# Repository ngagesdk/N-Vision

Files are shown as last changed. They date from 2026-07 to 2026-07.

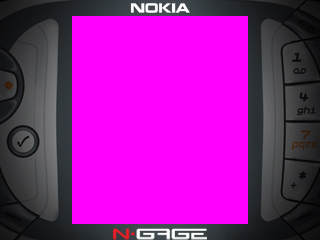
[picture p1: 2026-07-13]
firmware/assets/frame_buffer_rgb565.png

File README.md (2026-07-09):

N-Vision

# N-Vision

**A modern replacement for the original Nokia N-Gage screen capture hardware.**

## Overview

N-Vision is an open-source hardware project that aims to recreate the functionality
of the extremely rare screen capture device that was once used by Nokia during
promotional events, game demonstrations, and for recording official N-Gage gameplay
footage.

As original capture units have become virtually impossible to find, preserving and
showcasing N-Gage software has become increasingly difficult. N-Vision provides a
modern alternative by tapping directly into the display interface without requiring
any modifications to the console itself.

The project uses a custom flexible PCB (FPC) that is installed between the N-Gage's
mainboard and LCD, allowing the display signals to be captured transparently.
A Raspberry Pi Pico 2 then decodes the display data in real time and outputs it over
DVI, making it suitable for recording, streaming, or development purposes.

## Features (Planned)

- Non-destructive installation using a custom flexible PCB
- Real-time LCD signal capture
- Display decoding on a Raspberry Pi Pico 2
- Digital DVI video output
- Open-source hardware and firmware
- Designed specifically for the Nokia N-Gage Classic

## Project Structure
 
| Directory | Description |
| :--- | :--- |
| [decoder/](decoder/) | Proof-of-concept decoder to toy around with display signals. |
| [firmware/](firmware/) | Firmware for the Raspberry Pi Pico 2 that captures and decodes the N-Gage display signals in real time. |
| [hardware/](hardware/) | Hardware design files for the custom flexible PCB that interfaces with the N-Gage display. | 

## Project Status

> **This project is currently under active development and is not yet complete.**

The hardware, firmware, and documentation are all works in progress. Expect incomplete
features, design changes, and occasional breaking updates as development continues.

## Contributing

Contributions are warmly welcomed.

Whether you have experience with hardware design, embedded development, reverse
engineering, signal analysis, documentation, or simply own test hardware, your help
is greatly appreciated. Every contribution helps move the project closer to becoming
a practical and accessible replacement for the original capture hardware.

If you'd like to contribute, feel free to open an issue, start a discussion, or submit
a pull request.

## Goals

- Preserve the ability to capture authentic Nokia N-Gage gameplay.
- Provide an affordable and reproducible alternative to the original Nokia capture
  hardware.
- Document the N-Gage display interface for future preservation efforts.
- Build an open platform that the community can improve and extend.

## License

N-Vision is released under a dual-license model:

- **Software** (firmware, utilities, and related source code) is licensed under the
  [**MIT License**](firmware/LICENSE.md).
- **Hardware** (schematics, PCB layouts, mechanical designs, and other hardware design
  files) is licensed under the
  [**CERN Open Hardware Licence Version 2 - Permissive (CERN-OHL-P v2)**](hardware/cern_ohl_p_v2.txt).

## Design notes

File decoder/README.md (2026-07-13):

# Nokia N-Gage LCD Protocol Documentation

## Overview

This document describes the LCD bus protocol used in the Nokia N-Gage (NEM-4).
The protocol is a synchronous, command-and-data serial bus that controls a
display with 176×208 pixel resolution and 12-bit color depth (4096 colors).

## Bus Architecture

The LCD bus consists of **10 signal lines**:

- **LCDCLK** - Master clock signal. All data transfers occur on the rising edge.
- **LCDM** - Mode flag (1 bit, separate control signal)
  - `1` = Pixel-data word
  - `0` = Command word
- **LCDDa0–LCDDa7** - 8-bit data bus (bits 0–7, respectively)

### Bus Byte Layout (MSB First)

LCDM is sampled independently from the 8-bit data bus:

```
Bit 7: LCDDa7     – Display data bus, bit 7
Bit 6: LCDDa6     – Display data bus, bit 6
Bit 5: LCDDa5     – Display data bus, bit 5
Bit 4: LCDDa4     – Display data bus, bit 4
Bit 3: LCDDa3     – Display data bus, bit 3
Bit 2: LCDDa2     – Display data bus, bit 2
Bit 1: LCDDa1     – Display data bus, bit 1
Bit 0: LCDDa0     – Display data bus, bit 0

Separate signal:
LCDM              – Mode: 1 = pixel-data word, 0 = command
```

## Command Words (LCDM = 0)

When **LCDM = 0**, bits 7–0 encode a control strobe. The payload is masked as:

```
LCD_PAYLOAD_MASK = 0xFF (bits 7–0)
```

### Defined Commands

#### LCDLLClk - Line Latch Clock (0x75)

- **Value**: `0x75` (binary: `0111_0101`)
- **Purpose**: Loads the target row address into the display controller
- **Followed by**: 4 data words containing row/region parameters:
  - `target_data[0]` - Primary parameter (usually row or starting row)
  - `target_data[1]` - Secondary parameter (reserved)
  - `target_data[2]` - Tertiary parameter (reserved)
  - `target_data[3]` - Quaternary parameter (reserved)

#### LCDDISPClk - Display Pixel Clock (0x5C)

- **Value**: `0x5C` (binary: `0101_1100`)
- **Purpose**: Enters pixel-data transmission mode
- **Followed by**: One or more pixel-data words (LCDM = 1) until the
  next command

## Data Words (LCDM = 1)

When **LCDM = 1**, a data word is transmitted. The payload is:

```
LCD_PAYLOAD_MASK = 0xFF (bits 7–0)
```

### Pixel Data Format

Pixel data is encoded using **4-bit nibbles** (half-bytes).
Each transmitted byte contains **two nibbles**:

- **High nibble** = bits 7–4 (contains upper data bits)
- **Low nibble** = bits 3–0 (contains lower data bits)

Each nibble represents 4 bits of display information:

```
High nibble: [LCDDa7 | LCDDa6 | LCDDa5 | LCDDa4]
Low nibble:  [LCDDa3 | LCDDa2 | LCDDa1 | LCDDa0]
```

### Color Encoding (12-bit Depth)

The display uses **12-bit RGB color** (4 bits per color channel, 4,096 total colors). Three consecutive nibbles encode one pixel, with each nibble's 4 bits mapping directly to one color channel:

1. **Three consecutive data nibbles** encode one pixel:
   - `n0` - Red channel (R[3:0])
   - `n1` - Green channel (G[3:0])
   - `n2` - Blue channel (B[3:0])

2. **Direct MSB Encoding** (bit 3 in each nibble):

   Bit 3 of every nibble is always used directly as the MSB of its respective color channel; no cross-nibble prediction or column-position dependency:
   - R[3] = `n0[3]`
   - G[3] = `n1[3]`
   - B[3] = `n2[3]`

3. **Final RGB Value** (4 bits per channel, expanded to 8-bit):

   ```
   R = n0 * 16  ->  [0, 240] in 8-bit (4-bit -> 8-bit expansion)
   G = n1 * 16  ->  [0, 240] in 8-bit (4-bit -> 8-bit expansion)
   B = n2 * 16  ->  [0, 240] in 8-bit (4-bit -> 8-bit expansion)
   ```

## Frame Structure

A complete frame transmission follows this sequence:

1. **LCDLLClk command** (0x75 + 4 data words)
   - Sets the target row/region
   - Resets the pixel buffer for the new frame

2. **LCDDISPClk command** (0x5C)
   - Enters pixel-data mode
   - Accumulated pixel data begins

3. **Pixel data words** (LCDM = 1)
   - Multiple bytes containing encoded pixel data
   - Each byte contains 2 nibbles
   - Decodable in groups of 3 consecutive nibbles (1 pixel)

4. **Next command** (LCDLLClk or other)
   - Triggers output of accumulated pixel data
   - If LCDLLClk: new frame starts

## Timing

- All data transfers occur on the **rising edge** of **LCDCLK**
- There is no specified minimum clock rate or setup/hold time in this protocol documentation
- One complete frame requires multiple clock cycles

## Resolution and Output

- **Display dimensions**: 176 × 208 pixels
- **Color depth**: 12-bit RGB (4 bits per channel, 4,096 possible colors)
- **Total pixels per frame**: 36,608
- **Color encoding**: Direct nibble scheme (see Color Encoding section)

## Example: Reading a Frame

1. LCDCLK rising edge: LCDLLClk command (0x75) received -> state = LCDLLClk
2. LCDCLK rising edge: Data word 0 (target row) -> target_data[0]
3. LCDCLK rising edge: Data word 1 -> target_data[1]
4. LCDCLK rising edge: Data word 2 -> target_data[2]
5. LCDCLK rising edge: Data word 3 -> target_data[3]
6. LCDCLK rising edge: LCDDISPClk command (0x5C) received -> state = LCDDISPClk, start pixel accumulation
7. LCDCLK rising edge (multiple): Pixel data words received
8. (Next command or end of stream): Trigger decode and frame output

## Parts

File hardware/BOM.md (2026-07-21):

# Bill of materials

- [Molex 0555600168](https://www.molex.com/molex/products/part-detail/pcb_headers/0555600168)  ([Digi-Key](https://www.digikey.com/short/nrwqm2ht))
- [Molex 0547220164](https://www.molex.com/molex/products/part-detail/pcb_receptacles/0547220164) ([Digi-Key](https://www.digikey.com/short/298jd1bj))
- [Molex 5051101692](https://www.molex.com/en-us/products/part-detail/5051101692) ([Digi-Key](https://www.digikey.de/short/q1pv8zdh))

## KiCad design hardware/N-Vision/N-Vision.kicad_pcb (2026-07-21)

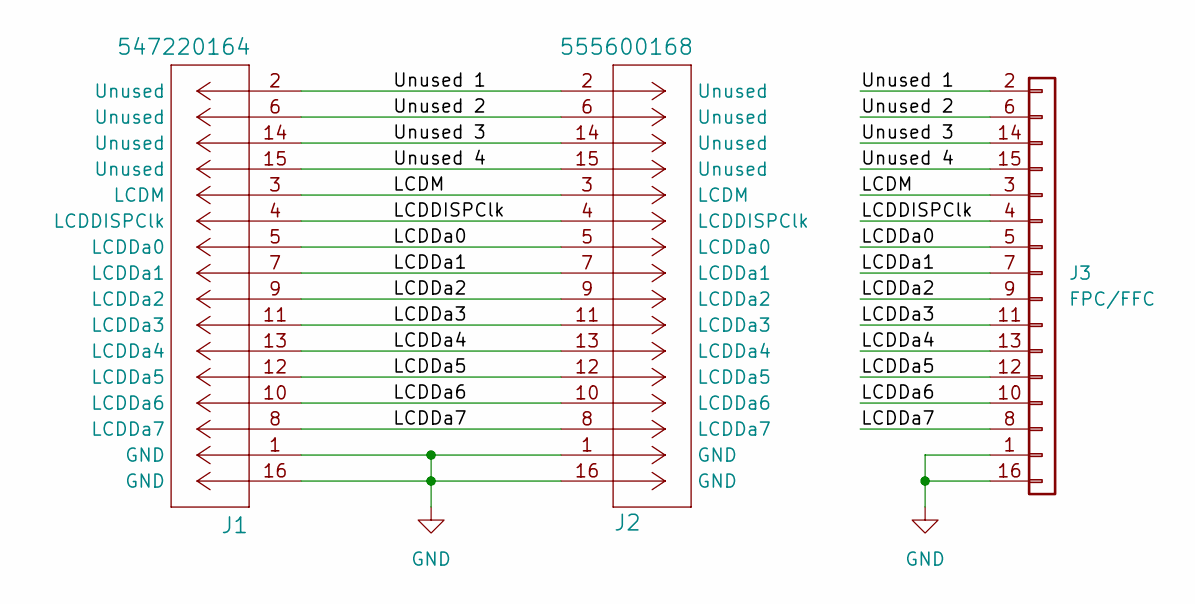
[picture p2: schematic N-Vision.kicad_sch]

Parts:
J1: 547220164; CONN_54722-0164_MOL
J2: 555600168; CONN_55560-0168_MOL
J3: FPC/FFC; FPC-16P-0.5mm

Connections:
/LCDDISPClk: J1.4 (LCDDISPClk), J2.4 (LCDDISPClk), J3.4
/LCDDa0: J1.5 (LCDDa0), J2.5 (LCDDa0), J3.5
/LCDDa1: J1.7 (LCDDa1), J2.7 (LCDDa1), J3.7
/LCDDa2: J1.9 (LCDDa2), J2.9 (LCDDa2), J3.9
/LCDDa3: J1.11 (LCDDa3), J2.11 (LCDDa3), J3.11
/LCDDa4: J1.13 (LCDDa4), J2.13 (LCDDa4), J3.13
/LCDDa5: J1.12 (LCDDa5), J2.12 (LCDDa5), J3.12
/LCDDa6: J1.10 (LCDDa6), J2.10 (LCDDa6), J3.10
/LCDDa7: J1.8 (LCDDa7), J2.8 (LCDDa7), J3.8
/LCDM: J1.3 (LCDM), J2.3 (LCDM), J3.3
/Unused 1: J1.2 (Unused), J2.2 (Unused), J3.2
/Unused 2: J1.6 (Unused), J2.6 (Unused), J3.6
/Unused 3: J1.14 (Unused), J2.14 (Unused), J3.14
/Unused 4: J1.15 (Unused), J2.15 (Unused), J3.15
GND: J1.1 (GND), J1.16 (GND), J2.1 (GND), J2.16 (GND), J3.1, J3.16

Board: 2 copper layers, 3 parts (2 on the bottom side), 15 nets, no tracks yet.

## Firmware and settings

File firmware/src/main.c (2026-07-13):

/** @file main.c
 *
 *  A PIO-based N-Gage LCD bus decoder.
 *
 *  Copyright (c) 2026, Michael Fitzmayer. All rights reserved.
 *  SPDX-License-Identifier: MIT
 *
 **/

#include <stdbool.h>
#include <stdint.h>
#include <stdio.h>
#include <stdlib.h>
#include <string.h>
#include "pico/stdlib.h"
#include "pico/multicore.h"
#include "hardware/clocks.h"
#include "hardware/irq.h"
#include "hardware/sync.h"
#include "hardware/gpio.h"
#include "hardware/vreg.h"

#include "dvi.h"
#include "dvi_serialiser.h"
#include "common_dvi_pin_configs.h"

#include "frame_buffer_rgb565.h"
#include "ngage.h"

// DVDD 1.2V (1.1V seems ok too)
#define VREG_VSEL  VREG_VOLTAGE_1_20
#define DVI_TIMING dvi_timing_640x480p_60hz

struct dvi_inst dvi0;

void core1_main()
{
    dvi_register_irqs_this_core(&dvi0, DMA_IRQ_0);
    while (queue_is_empty(&dvi0.q_colour_valid))
    {
        __wfe();
    }
    dvi_start(&dvi0);
    dvi_scanbuf_main_16bpp(&dvi0);
}

int main()
{
    vreg_set_voltage(VREG_VSEL);
    sleep_ms(10);
    set_sys_clock_khz(DVI_TIMING.bit_clk_khz, true);

    setup_default_uart();

    dvi0.timing  = &DVI_TIMING;
    dvi0.ser_cfg = DVI_DEFAULT_SERIAL_CONFIG;
    dvi_init(&dvi0, next_striped_spin_lock_num(), next_striped_spin_lock_num());

    // Core 1 will wait until it sees the first colour buffer, then
    // start up the DVI signalling.
    multicore_launch_core1(core1_main);

    // Initialise the PIO-based N-Gage LCD bus decoder.
    ngage_lcd_init();

    // Pass out pointers into our preprepared image, discard the
    // pointers when returned to us.
    static uint16_t scanline_buf[FRAME_WIDTH];

    while(true)
    {
        for (uint curr_line = 0; curr_line < FRAME_HEIGHT; ++curr_line)
        {
            uint16_t* scanline;

            // Drain the PIO FIFO every scanline to minimise data loss.
            update_display_buffer();

            if (curr_line >= DISPLAY_OFFSET_Y &&
                curr_line <  DISPLAY_OFFSET_Y + NGAGE_DISPLAY_HEIGHT)
            {
                // Composite: start from the frame buffer background, then
                // overlay the live N-Gage display region without modifying
                // frame_buffer_rgb565 itself.
                uint disp_line = curr_line - DISPLAY_OFFSET_Y;
                memcpy(scanline_buf,
                       &((uint16_t*)frame_buffer_rgb565)[curr_line * FRAME_WIDTH],
                       FRAME_WIDTH * sizeof(uint16_t));
                memcpy((char*)scanline_buf + DISPLAY_OFFSET_X * 2,
                       display_buffer_rgb565 + disp_line * NGAGE_BUFFER_WIDTH,
                       NGAGE_BUFFER_WIDTH);
                scanline = scanline_buf;
            }
            else
            {
                scanline = &((uint16_t*)frame_buffer_rgb565)[curr_line * FRAME_WIDTH];
            }

            queue_add_blocking_u32(&dvi0.q_colour_valid, &scanline);
            while (queue_try_remove_u32(&dvi0.q_colour_free, &scanline));
        }
    }
}

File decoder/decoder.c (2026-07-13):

/** @file decoder_csv.c
 *
 *  CSV variant of the Nokia N-Gage LCD framebuffer decoder.
 *
 *  Reads a libsigrok4DSL CSV export (16 channels) instead of a
 *  raw binary dump and produces the same per-frame PNG files as
 *  decoder.c.
 *
 *  Expected CSV format (libsigrok4DSL):
 *    Lines beginning with ';' are comments and are ignored.
 *    The first non-comment line is the column header and is
 *    ignored.
 *
 *    Every data line: Time(s),ch0,ch1,...,ch15
 *    Channel values are 0 or 1; the timestamp column is ignored.
 *
 *  Copyright (c) 2026, Michael Fitzmayer. All rights reserved.
 *  SPDX-License-Identifier: MIT
 *
 **/

#include <direct.h>
#include <stdint.h>
#include <stdio.h>
#include <stdlib.h>
#include <string.h>

#define STB_IMAGE_WRITE_IMPLEMENTATION
#include "stb_image_write.h"

#define WIDTH        176
#define HEIGHT       208
#define TOTAL_PIXELS (WIDTH * HEIGHT)

/* =======================================================================
 * Each CH_xxx is the zero-based CSV column index (0-15) connected to the
 * named LCD bus signal.
 *
 *   +--------------------------------+
 *   |  0   1   2   3   4   5   6   7 |
 *   |  8   9  10  11  12  13  14  15 |
 *   +--------------------------------+
 *
 * ====================================================================== */
#define CH_LCDCLK 9  /* CSV column wired to LCDCLK                        */
#define CH_LCDM   1  /* CSV column wired to LCDM   (bus bit 7, mode flag) */
#define CH_LCDDa7 11 /* CSV column wired to LCDDa7 (bus bit 8)            */
#define CH_LCDDa6 12 /* CSV column wired to LCDDa6 (bus bit 6)            */
#define CH_LCDDa5 13 /* CSV column wired to LCDDa5 (bus bit 5)            */
#define CH_LCDDa4 6  /* CSV column wired to LCDDa4 (bus bit 4)            */
#define CH_LCDDa3 5  /* CSV column wired to LCDDa3 (bus bit 3)            */
#define CH_LCDDa2 4  /* CSV column wired to LCDDa2 (bus bit 2)            */
#define CH_LCDDa1 3  /* CSV column wired to LCDDa1 (bus bit 1)            */
#define CH_LCDDa0 2  /* CSV column wired to LCDDa0 (bus bit 0)            */

/* -----------------------------------------------------------------------
 * LCD bus signals:
 *   LCDM             – mode flag, handled separately from data bus
 *                      1 = pixel-data word, 0 = command word
 *
 * Display data bus (bits 7-0):
 *   bit 7 : LCDDa7   – display data bus, bit 7
 *   bit 6 : LCDDa6   – display data bus, bit 6
 *   bit 5 : LCDDa5   – display data bus, bit 5
 *   bit 4 : LCDDa4   – display data bus, bit 4
 *   bit 3 : LCDDa3   – display data bus, bit 3
 *   bit 2 : LCDDa2   – display data bus, bit 2
 *   bit 1 : LCDDa1   – display data bus, bit 1
 *   bit 0 : LCDDa0   – display data bus, bit 0
 *
 * Command words (LCDM = 0): bits 7-0 identify the control strobe asserted:
 *   LCDLLClk   0x75 – line-latch clock  (followed by target-row data words)
 *   LCDDISPClk 0x5C – display pixel clock (followed by pixel data words)
 * ----------------------------------------------------------------------- */
#define LCDM   0x80u /* LCDM mode flag (separate signal) */
#define LCDDa7 0x80u /* bit 7 */
#define LCDDa6 0x40u /* bit 6 */
#define LCDDa5 0x20u /* bit 5 */
#define LCDDa4 0x10u /* bit 4 */
#define LCDDa3 0x08u /* bit 3 */
#define LCDDa2 0x04u /* bit 2 */
#define LCDDa1 0x02u /* bit 1 */
#define LCDDa0 0x01u /* bit 0 */

#define LCDLLClk   0x75u /* line-latch clock strobe  (LCDM = 0)   */
#define LCDDISPClk 0x5Cu /* display pixel-clock strobe (LCDM = 0) */

/* Composite masks used in nibble decode */
#define LCD_PAYLOAD_MASK (LCDDa7 | LCDDa6 | LCDDa5 | LCDDa4 | LCDDa3 | LCDDa2 | LCDDa1 | LCDDa0) /* bits 7-0 */

#define MAX_CHANNELS 16
#define CSV_LINE_MAX 512

static uint8_t framebuf[HEIGHT * WIDTH * 3];

/*
 * Decode nibble-encoded pixel data and write it into framebuf.
 */
static void decode_and_draw(const uint8_t *imdata, size_t imdata_len, int y_offset)
{
    size_t nibble_count = imdata_len * 2;
    uint8_t *nib = (uint8_t *)malloc(nibble_count);
    if (!nib)
        return;

    for (size_t k = 0; k < imdata_len; k++)
    {
        nib[k * 2 + 0] = (imdata[k] >> 4) & 0xf; /* high: [LCDDa7 | LCDDa6 | LCDDa5 | LCDDa4] */
        nib[k * 2 + 1] = imdata[k] & 0xf;        /* low:  [LCDDa3 | LCDDa2 | LCDDa1 | LCDDa0] */
    }

    int coli = 0;
    size_t off = 0;

    while (nibble_count - off >= 3)
    {
        // [0, 15] to [0, 240], 4b to 8b expansion.
        int r = nib[off + 0] * 16;
        int g = nib[off + 1] * 16;
        int b = nib[off + 2] * 16;

        int cx = coli % WIDTH;
        int cy = y_offset + (coli / WIDTH);

        if (cx >= 0 && cx < WIDTH && cy >= 0 && cy < HEIGHT)
        {
            size_t idx = (size_t)((cy * WIDTH + cx) * 3);
            framebuf[idx + 0] = (uint8_t)r;
            framebuf[idx + 1] = (uint8_t)g;
            framebuf[idx + 2] = (uint8_t)b;
        }

        off += 3;
        coli += 1;
    }

    free(nib);
}

/*
 * Reconstruct a single bus byte from one CSV row's sampled channel values.
 * ch[i] is 1 if channel i is high, 0 if low.
 * NOTE: LCDM is handled separately; this returns only the data bits (7-0).
 */
static uint8_t channels_to_bus_byte(const int ch[MAX_CHANNELS])
{
    uint8_t b = 0;
    if (ch[CH_LCDDa7])
    {
        b |= LCDDa7;
    }
    if (ch[CH_LCDDa6])
    {
        b |= LCDDa6;
    }
    if (ch[CH_LCDDa5])
    {
        b |= LCDDa5;
    }
    if (ch[CH_LCDDa4])
    {
        b |= LCDDa4;
    }
    if (ch[CH_LCDDa3])
    {
        b |= LCDDa3;
    }
    if (ch[CH_LCDDa2])
    {
        b |= LCDDa2;
    }
    if (ch[CH_LCDDa1])
    {
        b |= LCDDa1;
    }
    if (ch[CH_LCDDa0])
    {
        b |= LCDDa0;
    }
    return b;
}

/*
 * Parse one CSV data line into ch[0..MAX_CHANNELS-1].
 * Modifies 'line' in place (strtok).
 *
 * Skips:
 *   - Comment lines  (first char ';')
 *   - The header line (first char 'T' for "Time(s)")
 *   - Blank lines
 *
 * Returns the number of channel values parsed, or -1 to skip the line.
 */
static int parse_csv_row(char *line, int ch[MAX_CHANNELS])
{
    if (line[0] == ';' || line[0] == 'T' ||
        line[0] == '\n' || line[0] == '\r' || line[0] == '\0')
    {
        return -1;
    }

    char *tok = strtok(line, ","); /* consume the timestamp field */
    if (!tok)
    {
        return -1;
    }

    int count = 0;
    while (count < MAX_CHANNELS && (tok = strtok(NULL, ",")) != NULL)
    {
        /* Skip leading whitespace */
        while (*tok && (*tok == ' ' || *tok == '\t'))
        {
            tok++;
        }
        /* Stop at trailing whitespace */
        char *end = tok;
        while (*end && *end != ' ' && *end != '\t' && *end != '\r' && *end != '\n')
        {
            end++;
        }
        *end = '\0';

        if (*tok)
        {
            ch[count++] = atoi(tok);
        }
        else
        {
            ch[count++] = 0; /* Ensure we capture all columns, even empty ones */
        }
    }

    return count;
}
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

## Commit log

2026-07-03 Initial commit.
    [nokia.csv]
2026-07-04 Update proof-of-concept decoder.
    [nokia.csv]
2026-07-04 Clean-up, add missing brackets, set to Pico 2.
2026-07-08 Add trace.csv
    [trace.csv]
2026-07-09 Update display protocol. Use unspecified LCDDa7 data line (which we can clearly see in the logic trace).
2026-07-13 Remove redundant interlacing from firmware. Fixes #1
    [main.c, ngage.c]
2026-07-21 Update footprints (one needed to be reversed)
    [N-Vision.kicad_pcb, N-Vision.kicad_sch]
2026-07-21 Update BOM, add FPC connector.
    [N-Vision.kicad_pcb, N-Vision.kicad_sch]
2026-07-21 Update center.
    [N-Vision.kicad_pcb]
